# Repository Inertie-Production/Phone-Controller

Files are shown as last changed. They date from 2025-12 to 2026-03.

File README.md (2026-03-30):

# Phone Controller
Front-closed

This is a phone controller design inspired by the Nintendo 3DS. We created this controller because we wanted to make a cheap and pocketable phone controller while learning a lot of new stuff in the process! 
You can view and download the 3D model [on our Onshape][onshape].

On this github, you will find the pcb source files & gerbers, the code that
needs to be loaded on the controller and a BOM.

Once built, to use this controller, you can just clamp your phone on it, turn the power on with the switch and connect to it via bluetooth. 
Despite being very thin, this controller includes all the features of a full-size controller :
- 11 buttons with silent mechanical switches
- A D-pad
- 2 dual-axis joysticks
- 2 analog Hall effect triggers or 2 mechanical switches triggers
The 4 buttons on the back of the controller are the sticks buttons and the bumpers.

Every file of this repository and the Onshape project are licensied under the
GPL v3 license, see [`LICENSE`](./LICENSE) for details.

[onshape]: https://cad.onshape.com/documents/3e0c9ef397f91415fa372e0c/w/6f6e95703b5b2ee9676d2bfe/e/8a00a41f1ee7d469ca8e343f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

## Screenshots

back-closed
Back-open
Front-open

## BOM

| Type | Name | Description | Qtt needed | Link |
|---|---|---|---|---|
|Sticks|New 3DS XL Sticks|Nintendo new 3DS XL joysticks|2|2: https://www.alibaba.com/product-detail/Analog-Joystick-for-New-3DS-XL_1600274819879.html ; https://fr.aliexpress.com/item/1005006359586643.html + https://www.alibaba.com/product-detail/Thumb-Stick-for-3DS-3DS-XL_1601603454755.html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 |
|Screws|M1.4|Nintendo 3DS joystick screws (8mm Long x 1.5mm x 2.5mm) | 4 | https://fr.aliexpress.com/item/1005002364189187.html |
| | M2|4mm countersunk screws (for closing the back panel)|9|https://fr.aliexpress.com/item/1005008709978631.html |
||M2.5|5mm round/dome screws (max head height: 1.8mm) to fix the PCB|5|https://fr.aliexpress.com/item/1005008709978631.html |
|Buttons|SS-12D00 |SS-12D00 2mm shaft slide switch (power)|1|https://fr.aliexpress.com/item/1005008489387043.html |
||Buttons|6x6x3.5mm 2 pins (silent) mouse switches (ex: HUANO Mute Button 6 × 6 × 3.5mm; Kailh Mini 6.2mm Silent Micro Switches)|11|https://fr.aliexpress.com/item/1005005681410178.html |
||SKRWADE030|SKRWADE030 tactile buttons|4|https://fr.aliexpress.com/item/4001125555481.html |
|Triggers|SS49E|SS49E Hall effect sensors|2|https://fr.aliexpress.com/item/1005006001710265.html |
||Magnets|round 5x2mm magnets|2|https://fr.aliexpress.com/item/1005010155029417.html |
||Springs|springs (15×4mm)|2|https://fr.aliexpress.com/item/1005005402501364.html |
|Electronic|603030|603030 LiPo battery (30 × 30 × 6mm)|1|https://www.alibaba.com/product-detail/Lipo-603030-3-7V-600mAh-Rechargeable_1601168807381.html ; https://fr.aliexpress.com/item/1005007958724149.html |
||Resistors|10kΩ resistor (0805)|4|https://fr.aliexpress.com/item/1005006144658512.html |
|||200 kΩ resistors (0805)|2|https://fr.aliexpress.com/item/1005008666573344.html |
||BAT54C|BAT54C diodes|8|https://fr.aliexpress.com/item/1005006228736157.html |
||Seeed studio|Seeed Studio XIAO ESP32-S3 Plus and an antenna|1|https://www.seeedstudio.com/Seeed-Studio-XIAO-ESP32S3-Plus-p-6361.html ; https://fr.aliexpress.com/item/1005008329745247.html |
||100 nF 0805|100 nF capacitor (0805)|1|https://fr.aliexpress.com/item/1005006142309480.html
||PCB|The PCB|1|https://cart.jlcpcb.com/fr/quote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 |
|Plastic|3D printer filament|in grams, full estimation to check|300|

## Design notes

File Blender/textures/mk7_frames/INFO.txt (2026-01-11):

I have a full video if anyone wants it's 3min and 170Mo.
I don't see the point of putting it now so it's just frames.

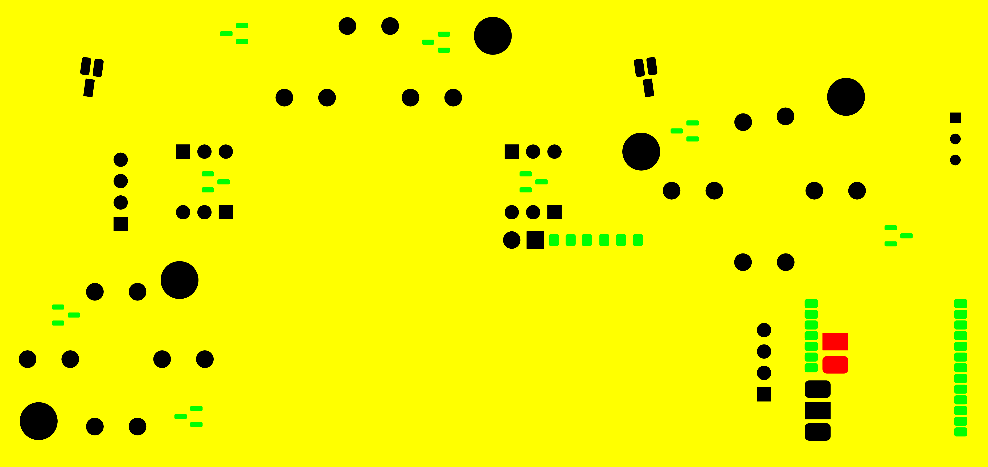
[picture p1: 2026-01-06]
Blender/textures/pcb_Mask.png

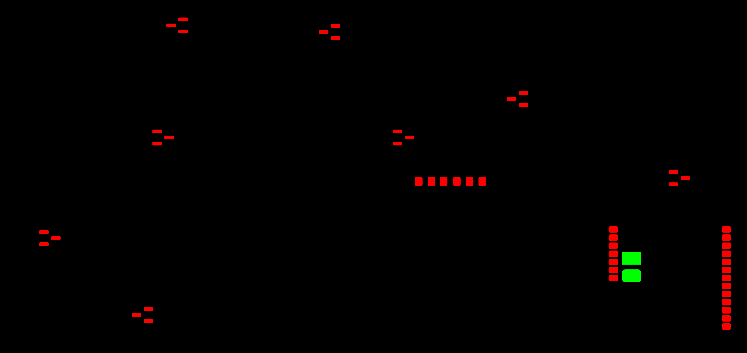
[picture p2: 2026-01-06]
Blender/textures/pcb_Paste.png

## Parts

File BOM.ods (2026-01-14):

Production costs
Category | Item | Description | Qtt per unit | Link |  |  | Cost |  | Min price min qtt (not really relevant)
 |  |  |  |  | Min Qtt | Price for qtt | Price/Qtt | Cost/unit if 2built
To buy |  |  |  |  |  |  |  | 2
Sticks | New 3DS XL Sticks | Nintendo new 3DS XL joysticks | 2 | 2: https://www.alibaba.com/product-detail/Analog-Joystick-for-New-3DS-XL_1600274819879.html ; https://fr.aliexpress.com/item/1005006359586643.html + https://www.alibaba.com/product-detail/Thumb-Stick-for-3DS-3DS-XL_1601603454755.html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 | 4 | €15,61 | €7,81 | €7,81 | €15,61
Screws | M1.4 | Nintendo 3DS joystick screws (8mm Long x 1.5mm x 2.5mm) | 4 | https://fr.aliexpress.com/item/1005002364189187.html | 50 | €1,23 | €0,10 | €0,62 | €1,23
 | M2 | 4mm countersunk screws (for closing the back panel) | 9 | https://fr.aliexpress.com/item/1005008709978631.html | 50 | €1,13 | €0,20 | €0,57 | €1,13
 | M2.5 | 5mm round/dome screws (max head height: 1.8mm) to fix the PCB | 5 | https://fr.aliexpress.com/item/1005008709978631.html | 50 | €1,37 | €0,14 | €0,69 | €1,37
Buttons | SS-12D00 | SS-12D00 2mm shaft slide switch (power) | 1 | https://fr.aliexpress.com/item/1005008489387043.html | 10 | €1,76 | €0,18 | €0,88 | €1,76
 | Buttons | 6x6x3.5mm 2 pins (silent) mouse switches (ex: HUANO Mute Button 6 × 6 × 3.5mm; Kailh Mini 6.2mm Silent Micro Switches) | 11 | https://fr.aliexpress.com/item/1005005681410178.html | 30 | €8,38 | €3,07 | €4,19 | €8,38
 | SKRWADE030 | SKRWADE030 tactile buttons | 4 | https://fr.aliexpress.com/item/4001125555481.html | 20 | €0,83 | €0,17 | €0,42 | €0,83
Triggers | SS49E | SS49E Hall effect sensors | 2 | https://fr.aliexpress.com/item/1005006001710265.html | 10 | €0,78 | €0,16 | €0,39 | €0,78
 | Magnets | round 5x2mm magnets | 2 | https://fr.aliexpress.com/item/1005010155029417.html | 50 | €1,73 | €0,07 | €0,87 | €1,73
 | Springs | springs (15×4mm) | 2 | https://fr.aliexpress.com/item/1005005402501364.html | 10 | €1,54 | €0,31 | €0,77 | €1,54
Electronic | 603030 | 603030 LiPo battery (30 × 30 × 6mm) | 1 | https://www.alibaba.com/product-detail/Lipo-603030-3-7V-600mAh-Rechargeable_1601168807381.html ; https://fr.aliexpress.com/item/1005007958724149.html | 2 | €8,84 | €4,42 | €4,42 | €8,84
 | Resistors | 10kΩ resistor (0805) | 4 | https://fr.aliexpress.com/item/1005006144658512.html | 470 | €1,08 | €0,01 | €0,54 | €1,08
 |  | 200 kΩ resistors (0805) | 2 | https://fr.aliexpress.com/item/1005008666573344.html | 470 | €1,17 | €0,00 | €0,59 | €1,17
 | BAT54C | BAT54C diodes | 8 | https://fr.aliexpress.com/item/1005006228736157.html | 100 | €1,31 | €0,10 | €0,66 | €1,31
 | Seeed studio | Seeed Studio XIAO ESP32-S3 Plus and an antenna | 1 | https://www.seeedstudio.com/Seeed-Studio-XIAO-ESP32S3-Plus-p-6361.html ; https://fr.aliexpress.com/item/1005008329745247.html | 1 | €6,99 | €6,99 | €6,99 | €6,99
 | 100 nF 0805 | 100 nF capacitor (0805) | 1 | https://fr.aliexpress.com/item/1005006142309480.html | 100 | €1,18 | €0,01 | €0,59 | €1,18
 | PCB | The PCB | 1 | https://cart.jlcpcb.com/fr/quote?stencilLayer=2&stencilWidth=100&stencilLength=100&stencilCounts=5&plateType=1 | 5 | €6,70 | €1,34 | €3,35 | €6,70
Consumable |  |  |  |  |  | Total | €25,07 | €34,31 | €61,63
Plastic | 3D printer filament | in grams, full estimation to check | 300 |  | 750 | €25,00 | €10,00 | €25,00 | €25,00
Total |  |  |  |  |  |  | €35,07 | €46,81 | €86,63
 |  |  |  |  |  |  | Big batch price | Per unit if 2 built | Min 1 unit price
 |  |  |  |  |  | The prices are optimised for 2 units (eg choices between 10 pcs or 100)
Actual testing costs
Category | Item | Reason | Qtt lost | Value lost
Consumable
Plastic | 3D printer filament | Tests | 0 | €0,00
Losts (destroyed during construction/tests) |  |  |  |  |  |  |  | Lost per unit | Lost per unit if build
Total

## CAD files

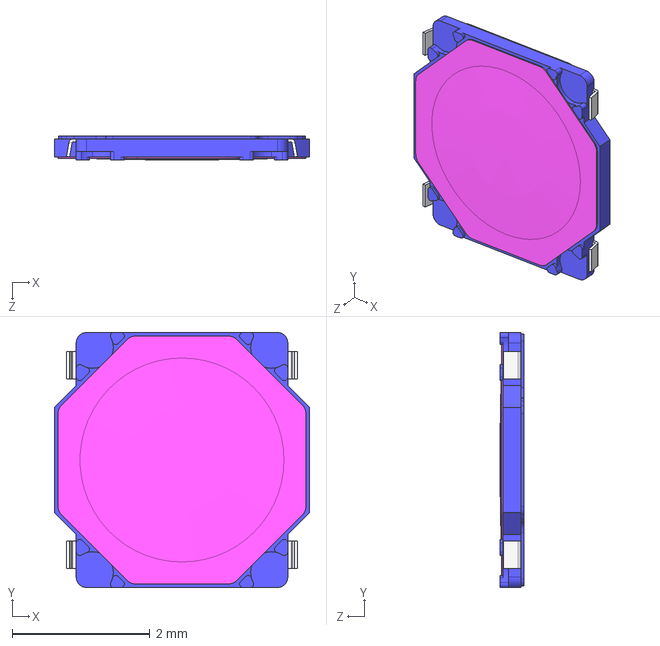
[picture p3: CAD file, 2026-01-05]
PCB/pcb_phone_controller/3Dmodels/SKRWADE030.STEP
3.70 x 3.70 x 0.35 mm

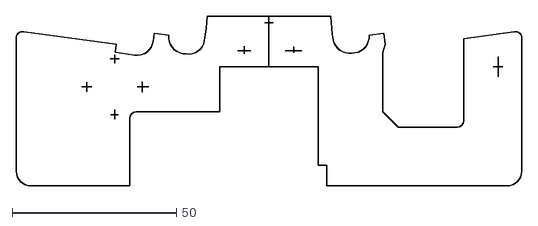
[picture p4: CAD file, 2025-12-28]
PCB/pcb_phone_controller/new_pcb_border.dxf
154.1 x 51.7

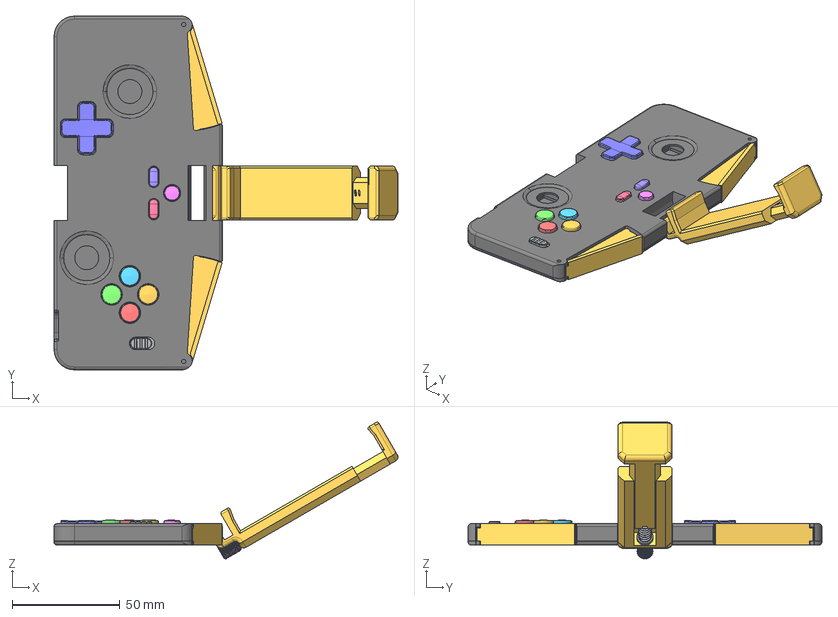
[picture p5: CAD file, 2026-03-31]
Phone Controller.step
159.5 x 164.1 x 63.4 mm

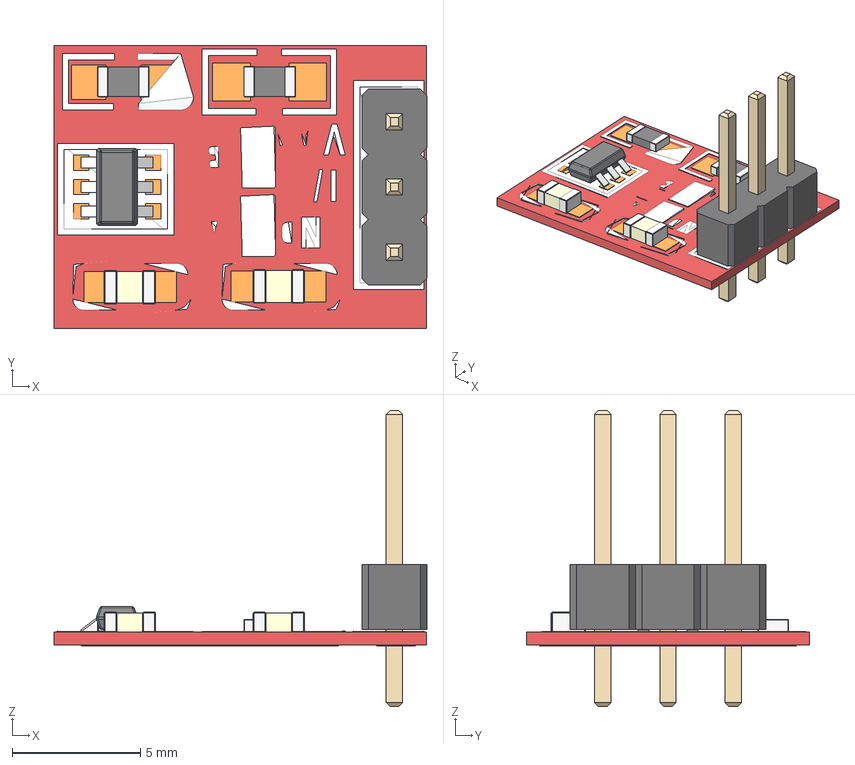
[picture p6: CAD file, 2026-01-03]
PCB/pcb_phone_controller/3Dmodels/TTP223.step
14.5 x 11.0 x 11.5 mm
PinHeader_1x03_P254mm_Vertical
\X2\0414043504420430043B044C\X0\
RES_0805 x 2
CAP_0805 x 2
sot23-6
sot23-6_001
sot23-6_002
sot23-6_003
sot23-6_004
sot23-6_005
sot23-6_006

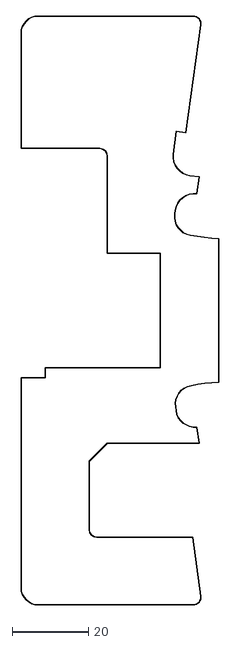
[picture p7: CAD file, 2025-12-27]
PCB/pcb_phone_controller/pcb_borders.dxf
51.7 x 154.1

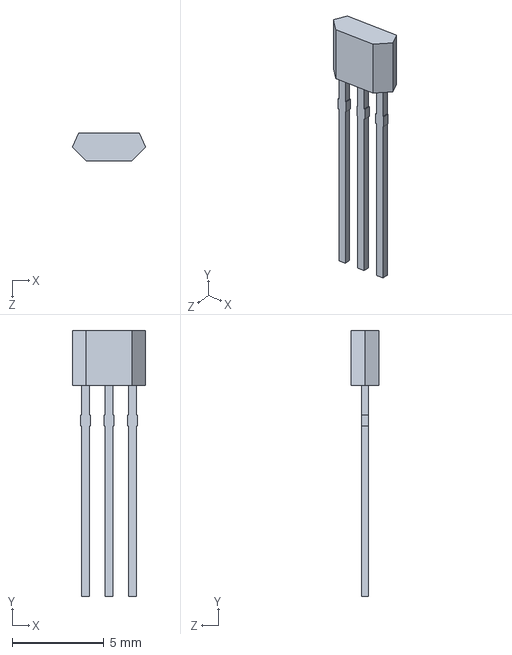
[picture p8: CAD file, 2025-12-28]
PCB/pcb_phone_controller/3Dmodels/SS49E Linear Hall Effect.STEP
4.00 x 14.5 x 1.52 mm

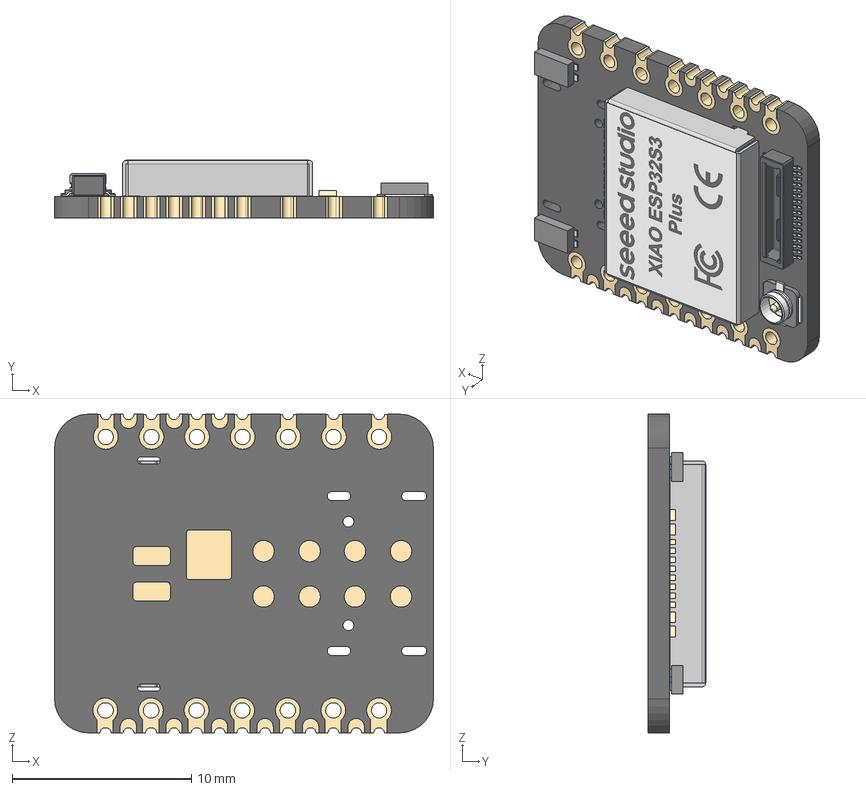
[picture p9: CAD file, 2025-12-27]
PCB/pcb_phone_controller/3Dmodels/XIAO ESP32S3 PLUS NO USB.step
21.1 x 3.22 x 17.8 mm
DF40C-30DP-0.4V_51_ v1
BOSS-EXTRUDE14_8_
BOSS-EXTRUDE7_4_
BOSS-EXTRUDE7_3_
BOSS-EXTRUDE14_4_
BOSS-EXTRUDE14_2_
BOSS-EXTRUDE14_11_
BOSS-EXTRUDE7_7_
BOSS-EXTRUDE14_9_
BOSS-EXTRUDE14_3_
BOSS-EXTRUDE14_7_
MIRROR2
BOSS-EXTRUDE14_5_
BOSS-EXTRUDE14_12_
BOSS-EXTRUDE7_8_
BOSS-EXTRUDE7_1_
BOSS-EXTRUDE14_10_
BOSS-EXTRUDE7_9_
BOSS-EXTRUDE14_6_
BOSS-EXTRUDE14_1_
Shield
Pins x 2
U.FL-R-SMT-1_10_ v1

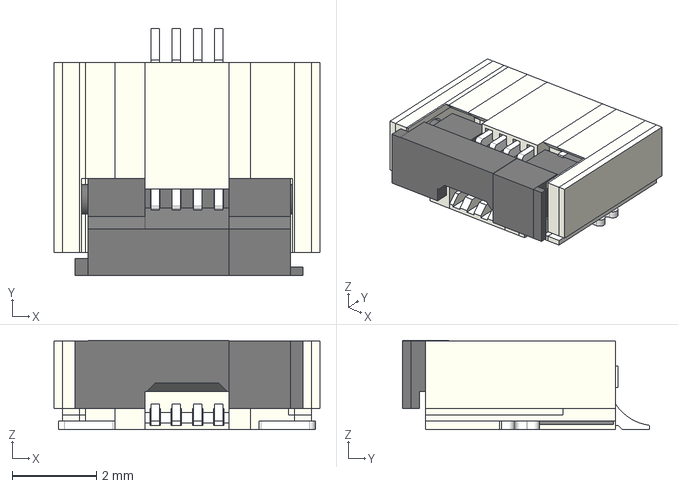
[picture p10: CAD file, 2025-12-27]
PCB/pcb_phone_controller/3Dmodels/FPC-4.stp
6.30 x 5.85 x 2.11 mm

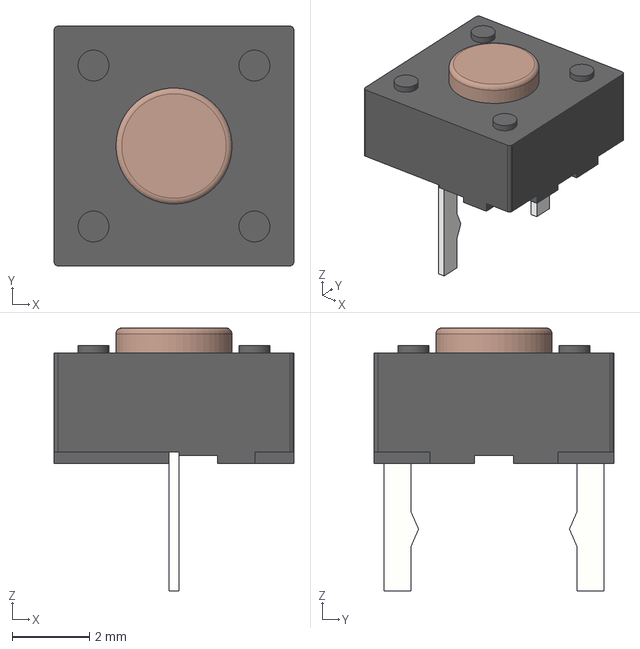
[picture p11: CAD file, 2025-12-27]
PCB/pcb_phone_controller/3Dmodels/Mini 6.2mm Silient Micro Switch v1.step
6.20 x 6.20 x 6.80 mm

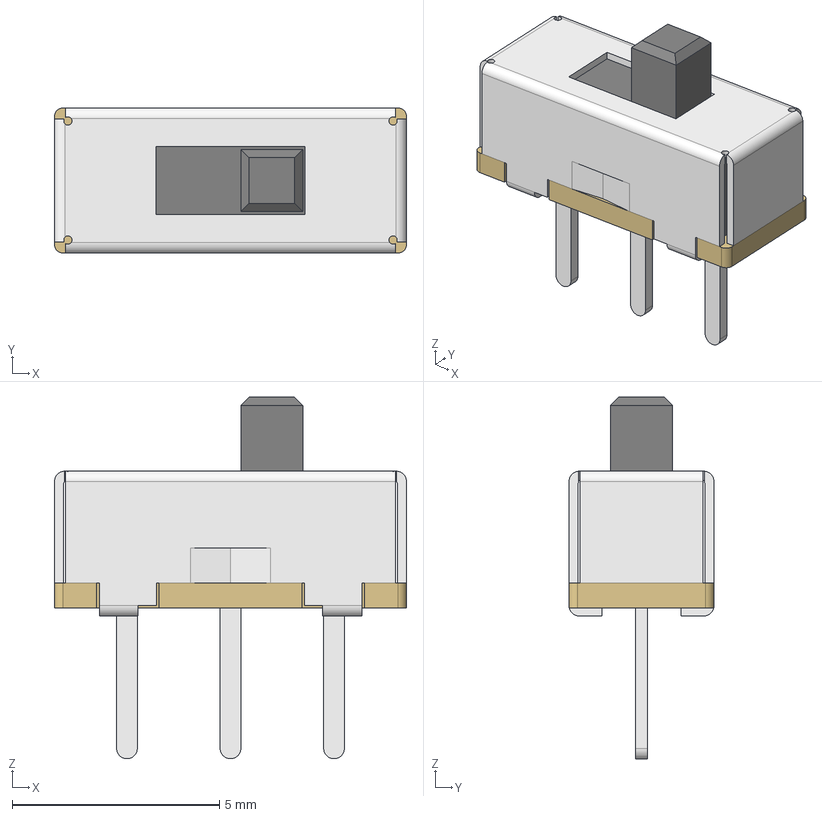
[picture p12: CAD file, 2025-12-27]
PCB/pcb_phone_controller/3Dmodels/switch power 2mm.step
8.50 x 3.50 x 8.73 mm

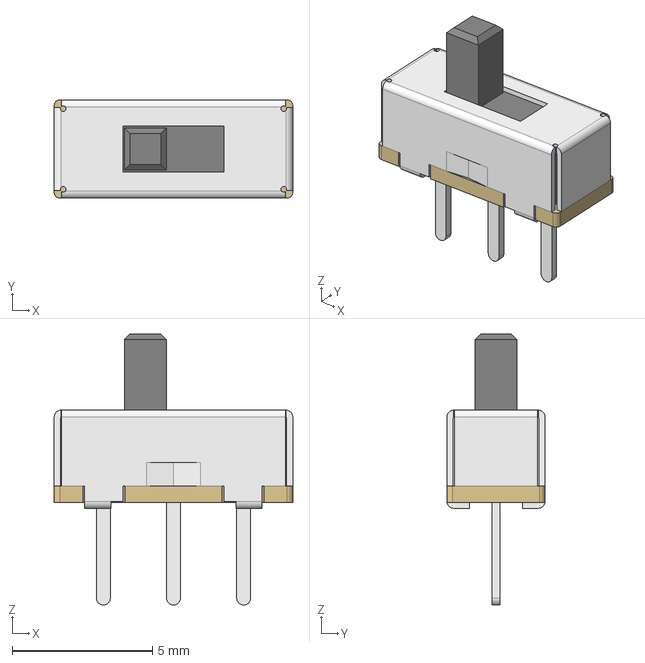
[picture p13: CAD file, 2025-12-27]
PCB/pcb_phone_controller/3Dmodels/SPDT slide switch SS12D00.step
8.50 x 3.50 x 9.66 mm

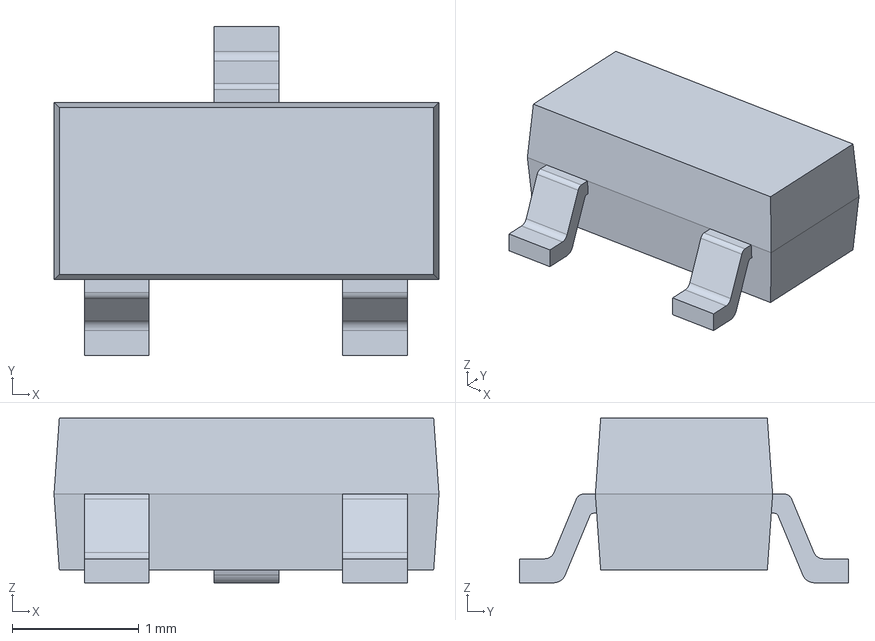
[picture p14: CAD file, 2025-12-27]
PCB/pcb_phone_controller/3Dmodels/BAT54S.STEP
3.04 x 2.60 x 1.30 mm

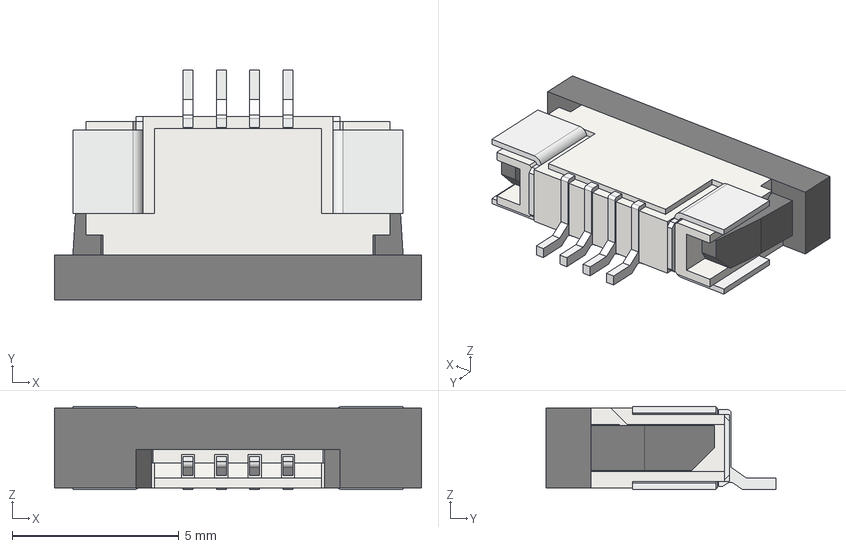
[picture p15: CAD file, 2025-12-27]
PCB/pcb_phone_controller/3Dmodels/FFC-connector.step
11.0 x 6.90 x 2.50 mm
FFC3B05-XX-T-housing
FFC3B05-XX-T-lugs
FFC3B05-XX-T-pin x 4
FFC3B05-XX-T-actuator

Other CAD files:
PCB/pcb_phone_controller/3Dmodels/SPDT slide switch SS12D00 2mm.step

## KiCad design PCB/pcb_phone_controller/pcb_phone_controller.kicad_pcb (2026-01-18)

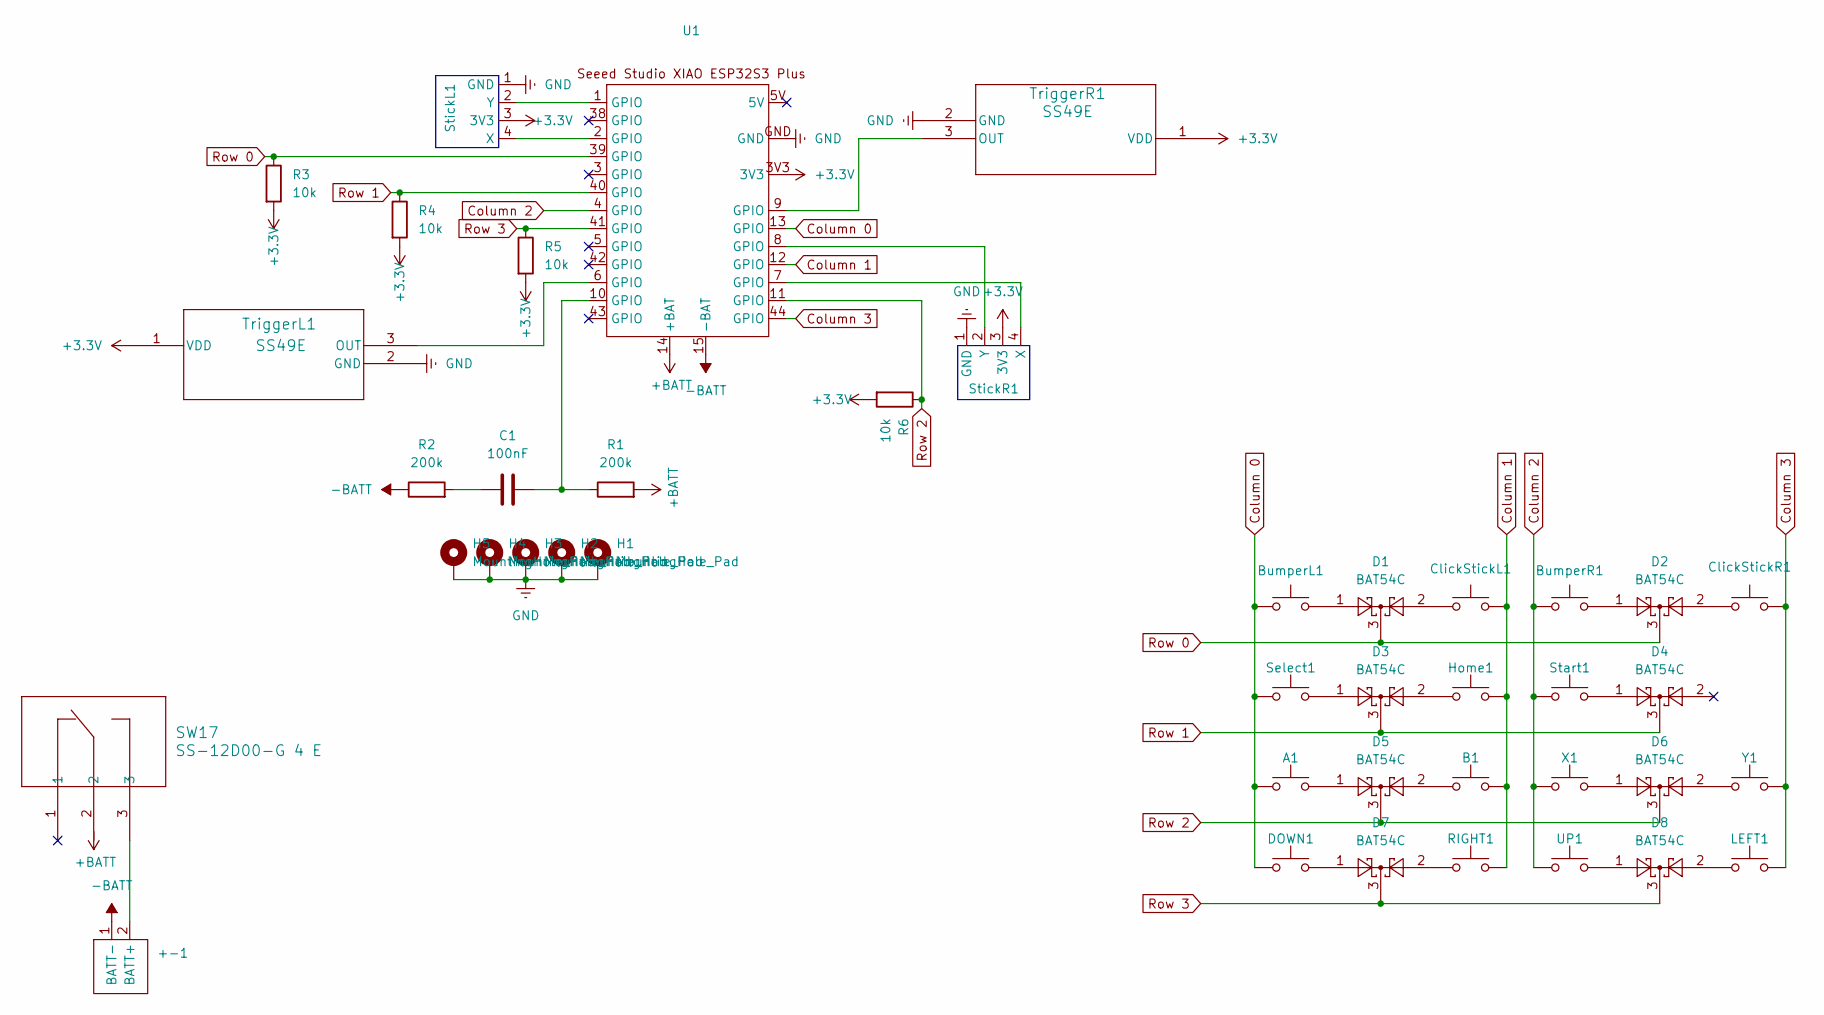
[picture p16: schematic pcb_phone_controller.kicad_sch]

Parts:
+-1: Battery_connection
A1: KAILH-MINI-SILENT-SWITCH
B1: KAILH-MINI-SILENT-SWITCH
BumperL1: Thin membrane button; SKRWADE030
BumperR1: Thin membrane button; SKRWADE030
C1: 100nF; C_0805_2012Metric_Pad1.18x1.45mm_HandSolder
ClickStickL1: Thin membrane button; SKRWADE030
ClickStickR1: Thin membrane button; SKRWADE030
D1, D2, D3, D4, D5, D6, D7, D8: BAT54C; SOT-23
DOWN1: KAILH-MINI-SILENT-SWITCH
H1, H2, H3, H4, H5: MountingHole_Pad; MountingHole_2.7mm_M2.5_ISO14580_Pad
Home1: KAILH-MINI-SILENT-SWITCH
LEFT1: KAILH-MINI-SILENT-SWITCH
R1, R2: 200k; R_0805_2012Metric_Pad1.20x1.40mm_HandSolder
R3, R4, R5, R6: 10k; R_0805_2012Metric_Pad1.20x1.40mm_HandSolder
RIGHT1: KAILH-MINI-SILENT-SWITCH
SW17: SS-12D00-G 4 E; 1P2T_SS-12D00_CNK
Select1: KAILH-MINI-SILENT-SWITCH
Start1: KAILH-MINI-SILENT-SWITCH
StickL1: PinHeader_1x04_P2.54mm_Vertical
StickR1: PinHeader_1x04_P2.54mm_Vertical
TriggerL1: SS49E; ss49e
TriggerR1: SS49E; ss49e
U1: Seeed Studio XIAO ESP32S3 Plus
UP1: KAILH-MINI-SILENT-SWITCH
X1: KAILH-MINI-SILENT-SWITCH
Y1: KAILH-MINI-SILENT-SWITCH

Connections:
+3.3V: R3.2, R4.2, R5.2, R6.2, StickL1.3 (3V3), StickR1.3 (3V3), TriggerL1.1 (VDD), TriggerR1.1 (VDD), U1.3V3
+BATT: R1.2, SW17.2, U1.14 (+BAT)
-BATT: +-1.1 (BATT-), R2.1, U1.15 (-BAT)
Column 0: A1.1, BumperL1.1, DOWN1.1, Select1.1, U1.13 (GPIO)
Column 1: B1.2, ClickStickL1.2, Home1.2, RIGHT1.2, U1.12 (GPIO)
Column 2: BumperR1.1, Start1.1, U1.4 (GPIO), UP1.1, X1.1
Column 3: ClickStickR1.2, LEFT1.2, U1.44 (GPIO), Y1.2
GND: H1.1, H2.1, H3.1, H4.1, H5.1, StickL1.1 (GND), StickR1.1 (GND), TriggerL1.2 (GND), TriggerR1.2 (GND), U1.GND
unnamed: +-1.2 (BATT+), SW17.3
unnamed: A1.2, D5.1
unnamed: B1.1, D5.2
unnamed: BumperL1.2, D1.1
unnamed: BumperR1.2, D2.1
unnamed: C1.1, R1.1, U1.10 (GPIO)
unnamed: C1.2, R2.2
unnamed: ClickStickL1.1, D1.2
unnamed: ClickStickR1.1, D2.2
unnamed: D3.1, Select1.2
unnamed: D3.2, Home1.1
unnamed: D4.1, Start1.2
unnamed: D6.1, X1.2
unnamed: D6.2, Y1.1
unnamed: D7.1, DOWN1.2
unnamed: D7.2, RIGHT1.1
unnamed: D8.1, UP1.2
unnamed: D8.2, LEFT1.1
unnamed: StickL1.4 (X), U1.2 (GPIO)
unnamed: StickL1.2 (Y), U1.1 (GPIO)
unnamed: StickR1.4 (X), U1.7 (GPIO)
unnamed: StickR1.2 (Y), U1.8 (GPIO)
unnamed: TriggerL1.3 (OUT), U1.6 (GPIO)
unnamed: TriggerR1.3 (OUT), U1.9 (GPIO)
Row 0: D1.3, D2.3, R3.1, U1.39 (GPIO)
Row 1: D3.3, D4.3, R4.1, U1.40 (GPIO)
Row 2: D5.3, D6.3, R6.1, U1.11 (GPIO)
Row 3: D7.3, D8.3, R5.1, U1.41 (GPIO)

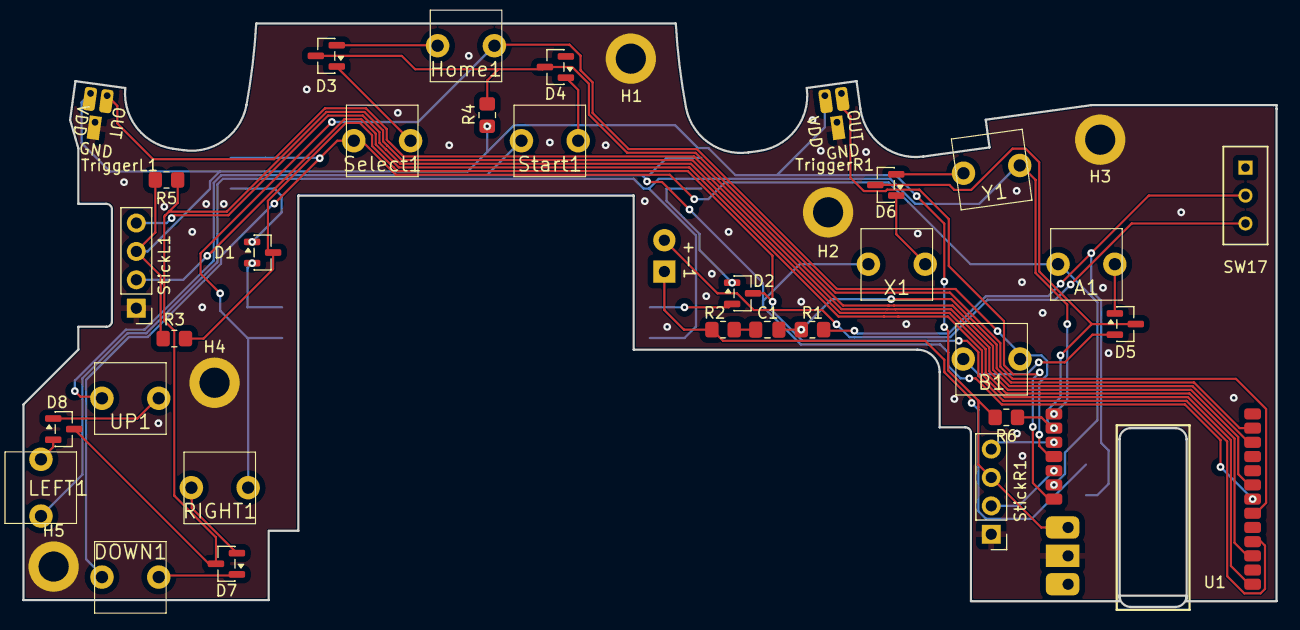
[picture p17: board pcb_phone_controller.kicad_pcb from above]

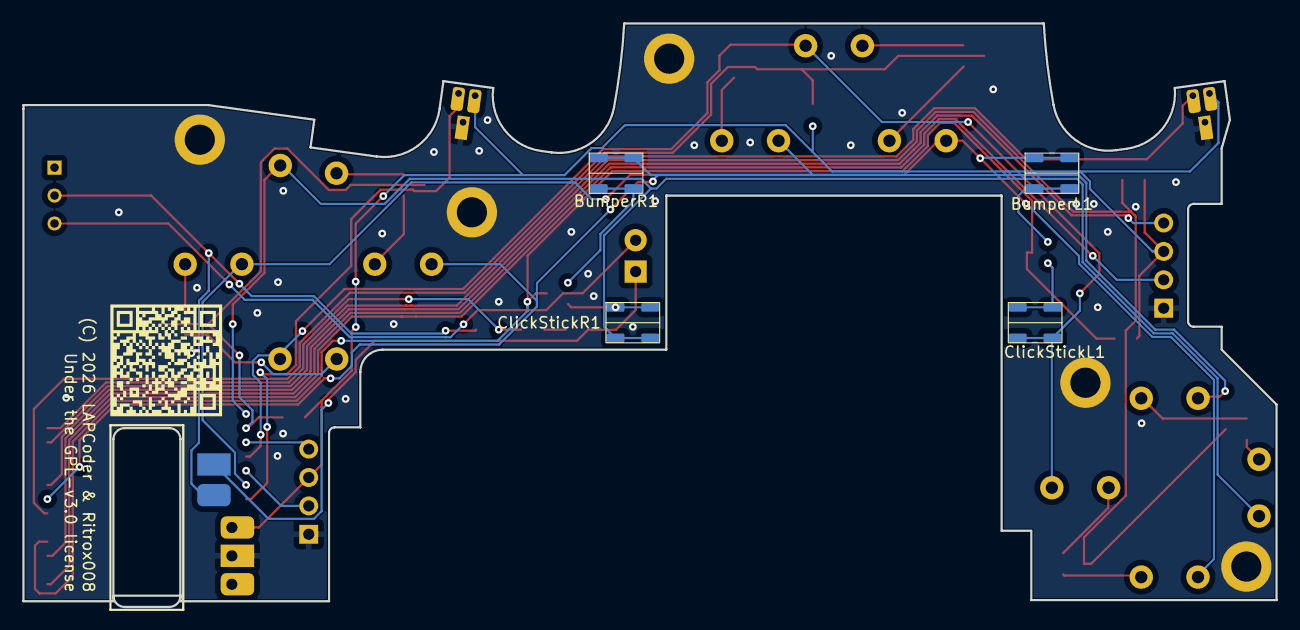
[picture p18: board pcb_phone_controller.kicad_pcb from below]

Board: 2 copper layers, 112.1 x 52.2 mm, 42 parts (4 on the bottom side), 36 nets.

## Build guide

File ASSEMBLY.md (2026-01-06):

# Assembly

How to create the project?

## Parts

See [`BOM.md`](./BOM.md) for the parts you need.

## 3D print

Download the Onshape, convert the parts to different STL
(or remind me to put the STL here directly) then 3D-print them.

## PCB

Use the Gerber files to make the PCB.
To mount it, first solder pins on the 3 vias of the PCB where the
microcontroller will be.

You then need to solder 2 wires on the Batt+ and Batt- on the back of the
microcontroller. Don't forget to hotglue / epoxy them so the pad doesn't
detach under load.
You can now pass those wires throught the big hole of the PCB, and put the
microcontroller in the correct pins.

Finally solder all remaining pads then the other components.

You should probably start by the resistors and diodes, then the back buttons
and then the front buttons and hall effects.

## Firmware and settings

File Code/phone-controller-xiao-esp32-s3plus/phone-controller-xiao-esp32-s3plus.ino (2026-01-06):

#include <Arduino.h>
#include "lib/ESP32-BLE-Gamepad-0.7.3/BleGamepad.h"
#include "lib/ESP32-BLE-Gamepad-0.7.3/Preferences.h"

/* ============================================================
 * ========================= DEFINES ==========================
 * ============================================================
 */

#define BATTERY_PIN				10
#define DIVIDER_RATIO			2.0f

#define BATTERY_UPDATE_INTERVAL	10000UL

#define STICK_AXIS_MIN			-32767
#define STICK_AXIS_MAX			32767

#define ADC_MAX_VALUE			4095
#define ADC_REF_VOLTAGE			3.3f

/* ============================================================
 * ========================= GLOBALS ==========================
 * ============================================================
 */

Preferences prefs;
BleGamepad bleGamepad("PhoneController", "Inertie Production", 100);
// Placeholders:       deviceName         Manufacturer

/* -------------------- Button Matrix -------------------- */

#define MATRIX_ROWS	4
#define MATRIX_COLS	4

int RowPins[MATRIX_ROWS] = { 39, 40, 11, 41 };
int ColPins[MATRIX_COLS] = { 13, 12, 4, 44 };

/*
	row0: BumperL, StickL, BumperR, StickR
	row1: Select, Home, Start
	row2: A, B, X, Y
	row3: Down, Right, Up, Left
*/
int ButtonMatrix[MATRIX_ROWS][MATRIX_COLS] =
{
	{ BUTTON_5,  BUTTON_7,  BUTTON_6,  BUTTON_8  },
	{ BUTTON_11, BUTTON_9,  BUTTON_10, 0         },
	{ BUTTON_1,  BUTTON_2,  BUTTON_3,  BUTTON_4  },
	{ BUTTON_12, BUTTON_13, BUTTON_14, BUTTON_15 }
};

/* -------------------- Joysticks -------------------- */

#define STICK_LY	A0
#define STICK_LX	A1
#define STICK_RY	A9
#define STICK_RX	A8

int StickLMaxX = 880;
int StickLMinX = 143;
int StickLMaxY = 880;
int StickLMinY = 143;

int StickRMaxX = 880;
int StickRMinX = 143;
int StickRMaxY = 880;
int StickRMinY = 143;

int StickNeutralDeadzone = 4000;

/* -------------------- Triggers -------------------- */

#define TRIGGER_L	A5
#define TRIGGER_R	A10

bool UseAnalogTriggers = true;

int TriggerMinL = 540;
int TriggerMaxL = 790;
int TriggerMinR = 540;
int TriggerMaxR = 790;

int MappedTriggerL = 0;
int MappedTriggerR = 0;

/* -------------------- Battery -------------------- */

unsigned long LastBatteryUpdate = 0;

/* ============================================================
 * ========================= HELPERS ==========================
 * ============================================================
 */

// Clamp value inside bounds
int ClampValue(int value, int minValue, int maxValue)
{
	if (value < minValue) return minValue;
	if (value > maxValue) return maxValue;
	return value;
}

// TODO: Allow configurable voltage curve (Li-Ion is not linear)
int ReadBatteryPercentage()
{
	int raw = analogRead(BATTERY_PIN);

	float voltage = (raw / (float)ADC_MAX_VALUE) * ADC_REF_VOLTAGE;
	voltage *= DIVIDER_RATIO;

#define BATTERY_MIN_VOLTAGE	3.2f
#define BATTERY_MAX_VOLTAGE	4.2f

	voltage = constrain(voltage, BATTERY_MIN_VOLTAGE, BATTERY_MAX_VOLTAGE);

	float percent = ((voltage - BATTERY_MIN_VOLTAGE) /
					(BATTERY_MAX_VOLTAGE - BATTERY_MIN_VOLTAGE)) * 100.0f;

	return (int)roundf(percent);
}

// Apply deadzone and re-scale axis
int16_t ApplyDeadzone(int16_t value, int16_t deadzone)
{
	if (abs(value) < deadzone)
	{
		return 0;
	}

	if (value > 0)
	{
		return map(value, deadzone, STICK_AXIS_MAX, 0, STICK_AXIS_MAX);
	}

	return map(value, -deadzone, STICK_AXIS_MIN, 0, STICK_AXIS_MIN);
}

// Scan one button from matrix
bool IsButtonPressed(int row, int col)
{
	digitalWrite(RowPins[row], LOW);
	delayMicroseconds(5);

	bool pressed = (digitalRead(ColPins[col]) == LOW);

	digitalWrite(RowPins[row], HIGH);
	return pressed;
}

/* ============================================================
 * ======================= CALIBRATION ========================
 * ============================================================
 */

// TODO: Add timeout / cancel option via button
void CalibrateTriggers()
{
	Serial.println("Use analog triggers? [Y/N]");

	while (!Serial.available()) { }

	char input = Serial.read();

	if (input == 'n' || input == 'N')
	{
		UseAnalogTriggers = false;

		prefs.begin("calibration", false);
		prefs.putBool("UseAnalogTriggers", UseAnalogTriggers);
		prefs.end();

		return;
	}

	UseAnalogTriggers = true;

	TriggerMaxL = 0;
	TriggerMaxR = 0;

	Serial.println("Fully press both triggers for 3 seconds");

	unsigned long start = millis();

	while (millis() - start < 3000)
	{
		TriggerMaxL = max(TriggerMaxL, analogRead(TRIGGER_L));
		TriggerMaxR = max(TriggerMaxR, analogRead(TRIGGER_R));
		delay(100);
	}

	TriggerMinL = ADC_MAX_VALUE;
	TriggerMinR = ADC_MAX_VALUE;

	Serial.println("Release both triggers for 3 seconds");

	start = millis();

	while (millis() - start < 3000)
	{
		TriggerMinL = min(TriggerMinL, analogRead(TRIGGER_L));
		TriggerMinR = min(TriggerMinR, analogRead(TRIGGER_R));
		delay(100);
	}

	prefs.begin("calibration", false);
	prefs.putBool("UseAnalogTriggers", UseAnalogTriggers);
	prefs.putInt("TriggerMinL", TriggerMinL);
	prefs.putInt("TriggerMaxL", TriggerMaxL);
	prefs.putInt("TriggerMinR", TriggerMinR);
	prefs.putInt("TriggerMaxR", TriggerMaxR);
	prefs.end();
}

// TODO: Store neutral center calibration per stick
void CalibrateSticks()
{
	StickLMaxX = StickLMaxY = 0;
	StickRMaxX = StickRMaxY = 0;

	StickLMinX = StickLMinY = ADC_MAX_VALUE;
	StickRMinX = StickRMinY = ADC_MAX_VALUE;

	Serial.println("Rotate sticks fully for 5 seconds");

	unsigned long start = millis();

	while (millis() - start < 5000)
	{
		StickLMaxX = max(StickLMaxX, analogRead(STICK_LX));
		StickLMinX = min(StickLMinX, analogRead(STICK_LX));
		StickLMaxY = max(StickLMaxY, analogRead(STICK_LY));
		StickLMinY = min(StickLMinY, analogRead(STICK_LY));

		StickRMaxX = max(StickRMaxX, analogRead(STICK_RX));
		StickRMinX = min(StickRMinX, analogRead(STICK_RX));
		StickRMaxY = max(StickRMaxY, analogRead(STICK_RY));
		StickRMinY = min(StickRMinY, analogRead(STICK_RY));

		delay(50);
	}

	prefs.begin("calibration", false);
	prefs.putInt("StickLMaxX", StickLMaxX);
	prefs.putInt("StickLMinX", StickLMinX);
	prefs.putInt("StickLMaxY", StickLMaxY);
	prefs.putInt("StickLMinY", StickLMinY);
	prefs.putInt("StickRMaxX", StickRMaxX);
	prefs.putInt("StickRMinX", StickRMinX);
	prefs.putInt("StickRMaxY", StickRMaxY);
	prefs.putInt("StickRMinY", StickRMinY);
	prefs.end();
}

/* ============================================================
 * =========================== SETUP ==========================
 * ============================================================
 */

void setup()
{
	Serial.begin(115200);

	for (int i = 0; i < MATRIX_ROWS; i++)
	{
		pinMode(RowPins[i], OUTPUT);
		digitalWrite(RowPins[i], HIGH);
	}

	for (int i = 0; i < MATRIX_COLS; i++)
	{
		pinMode(ColPins[i], INPUT);
	}

	delay(100);

	if (IsButtonPressed(2, 0) && IsButtonPressed(3, 2))
	{
		Serial.println("== CALIBRATION MODE ==");
		CalibrateTriggers();
		CalibrateSticks();
		ESP.restart();
	}

	prefs.begin("calibration", true);

	UseAnalogTriggers = prefs.getBool("UseAnalogTriggers", true);

	TriggerMinL = prefs.getInt("TriggerMinL", TriggerMinL);
	TriggerMaxL = prefs.getInt("TriggerMaxL", TriggerMaxL);
	TriggerMinR = prefs.getInt("TriggerMinR", TriggerMinR);
	TriggerMaxR = prefs.getInt("TriggerMaxR", TriggerMaxR);

	StickNeutralDeadzone = prefs.getInt("StickNeutralDeadzone", StickNeutralDeadzone);

	prefs.end();

	bleGamepad.begin();
}

/* ============================================================
 * ============================ LOOP ==========================
 * ============================================================
 */

void loop()
{
	if (!bleGamepad.isConnected())
	{
		delay(10);
		return;
	}

	int lx = analogRead(STICK_LX);
	int ly = analogRead(STICK_LY);
	int rx = analogRead(STICK_RX);
	int ry = analogRead(STICK_RY);

	int16_t mappedLX = ApplyDeadzone(map(lx, StickLMinX, StickLMaxX, STICK_AXIS_MIN, STICK_AXIS_MAX), StickNeutralDeadzone);
	int16_t mappedLY = ApplyDeadzone(map(ly, StickLMinY, StickLMaxY, STICK_AXIS_MIN, STICK_AXIS_MAX), StickNeutralDeadzone);
	int16_t mappedRX = ApplyDeadzone(map(rx, StickRMinX, StickRMaxX, STICK_AXIS_MIN, STICK_AXIS_MAX), StickNeutralDeadzone);
	int16_t mappedRY = ApplyDeadzone(map(ry, StickRMinY, StickRMaxY, STICK_AXIS_MIN, STICK_AXIS_MAX), StickNeutralDeadzone);

	bleGamepad.setLeftThumb(mappedLX, mappedLY);
	bleGamepad.setRightThumb(mappedRX, mappedRY);

	if (UseAnalogTriggers)
	{
		MappedTriggerL = map(ClampValue(analogRead(TRIGGER_L), TriggerMinL, TriggerMaxL), TriggerMinL, TriggerMaxL, 0, STICK_AXIS_MAX);
		MappedTriggerR = map(ClampValue(analogRead(TRIGGER_R), TriggerMinR, TriggerMaxR), TriggerMinR, TriggerMaxR, 0, STICK_AXIS_MAX);
	}
	else
	{
		MappedTriggerL = digitalRead(TRIGGER_L) == LOW ? STICK_AXIS_MAX : 0;
		MappedTriggerR = digitalRead(TRIGGER_R) == LOW ? STICK_AXIS_MAX : 0;
	}

	bleGamepad.setLeftTrigger(MappedTriggerL);
	bleGamepad.setRightTrigger(MappedTriggerR);

	for (int row = 0; row < MATRIX_ROWS; row++)
	{
		digitalWrite(RowPins[row], LOW);

		for (int col = 0; col < MATRIX_COLS; col++)
		{
			int button = ButtonMatrix[row][col];

			if (!button) continue;

			if (digitalRead(ColPins[col]) == LOW)
			{
				bleGamepad.press(button);
			}
			else
			{
				bleGamepad.release(button);
			}
		}

		digitalWrite(RowPins[row], HIGH);
	}

	unsigned long now = millis();

	if (now - LastBatteryUpdate >= BATTERY_UPDATE_INTERVAL)
	{
		bleGamepad.setBatteryLevel(ReadBatteryPercentage());
		LastBatteryUpdate = now;
	}

	bleGamepad.sendReport();
	delay(10);
}

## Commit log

2025-12-25 Add library
    ESP32-BLE-Gamepad 7.3
2025-12-27 Add the PCB
    [BAT54S.STEP, FFC-connector.step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]
2025-12-28 PCB cleanup (libs and traces)
    [FMControllerSeed-B_Cu.gbr, FMControllerSeed-B_Mask.gbr, FMControllerSeed-B_Paste.gbr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]
2025-12-29 PCB shape and reroute to make space for sticks
    [pcb_phone_controller-B_Cu.gbr, pcb_phone_controller-B_Mask.gbr, pcb_phone_controller-B_Paste.gbr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]
2025-12-29 PCB shape refinement
    [pcb_phone_controller-B_Cu.gbr, pcb_phone_controller-B_Mask.gbr, pcb_phone_controller-B_Paste.gbr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]
2025-12-29 Revise BOM with updated components and specifications
    Updated the BOM to reflect changes in joystick types, added components including magnets and springs, and revised screw specifications.
2025-12-29 Revise README for Phone Controller details
    Updated the title and added information about PCB source files and code.
2026-01-02 Various fixes Add license on PCB Fix the hole Fix DRC Fix code tree Put back the drc-passed hall effect pads Beautify the BOM Add folders
    [BAT54S.STEP, FFC-connector.step, FPC-4.stp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]
2026-01-02 Update .gitignore and the Gerber files
    [new_pcb_border.dxf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]
2026-01-02 Add pads to connect the battery to the µcontroller + add assembly guide
    [pcb_phone_controller-B_Cu.gbr, pcb_phone_controller-B_Mask.gbr, pcb_phone_controller-B_Paste.gbr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]
2026-01-03 Add a 3D model for the TTP223
    [TTP223.step, pcb_phone_controller.kicad_pcb, pcb_phone_controller.kicad_sch]
2026-01-03 Quickfix: replace the labels on the PCB
    [pcb_phone_controller.kicad_pcb]
2026-01-05 Change capacitives buttons to digitals ones and add real pullup
    [pcb_phone_controller.kicad_pcb, pcb_phone_controller.kicad_sch]
2026-01-05 Add a 3D model for the back buttons
    [SKRWADE030.STEP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]
2026-01-06 Update the BOM to match the newest requirements
2026-01-06 Small fixes. The code is still not tested, hardware "supply" "issue" It means we don't have the seeed studio right now.
    [phone-controller-xiao-esp32-s3plus.ino]
2026-01-11 Update the BOM to a nice and clean spreadsheet
    [BOM.ods]
2026-01-11 Add the PCB in the BOM and make the PCB smaller
    [BOM.ods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]
2026-01-14 Update a bit the BOM and the gitignore
    [BOM.ods]
2026-01-16 Reroute the PCB to move the buttons
    [pcb_phone_controller-B_Cu.gbr, pcb_phone_controller-B_Mask.gbr, pcb_phone_controller-B_Paste.gbr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]
2026-01-18 Modify a bit the PCB
    [pcb_phone_controller-B_Cu.gbr, pcb_phone_controller-B_Mask.gbr, pcb_phone_controller-B_Paste.gbr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]
2026-03-30 Update README with BOM and button layout details
    Added a BOM to the README and clarified the button layout description.
2026-03-30 Enhance README with detailed controller features
    Expanded description of controller features and clarified button functionality.
2026-03-30 Add BOM in readme
    [BOM.csv]
2026-03-31 step for 3d printed parts
    [Phone Controller.step]

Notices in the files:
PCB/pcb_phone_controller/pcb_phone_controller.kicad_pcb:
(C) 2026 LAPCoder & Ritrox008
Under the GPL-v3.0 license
